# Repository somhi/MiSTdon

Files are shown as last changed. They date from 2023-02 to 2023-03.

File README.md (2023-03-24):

# MiSTdon - MiST addon 

This is a compendium of all that is needed to build a MiST prototype for any FPGA to be nearly compatible with the [MiST FPGA](https://github.com/mist-devel/mist-board/wiki).

Current status:

* [PCB design finished](MiSTdon.kicad/). Tests are Ok, but original firmware at 24 Mhz is giving bus noise, so **a** **modified firmware at 16 MHz is needed.**

* Working prototype made in a protoboard

* After a reset it stops working (see notes below) 
* Passive serial flashing of the FPGA has not been implemented as my FPGA does not have that possibility. I power supply the FPGA and MiST addon, then load the bitstream from the PC though JTAG.

Acknowledgements and thanks for help go to Jepalza, Volton and Manuferhi.

## Resources

* foroFPGA Jepalza's inspirational post http://www.forofpga.es/viewtopic.php?t=289

* MiST firmware
  * Source code https://github.com/mist-devel/mist-firmware
  
  * .bin latest binary firmware https://github.com/mist-devel/mist-binaries/tree/master/firmware
  
  * Flash firmware: [Atmel SAM-BA v2.18](https://www.microchip.com/developmenttools/ProductDetails/SAM-BA In-system Programmer). Follow [instructions](https://github.com/mist-devel/mist-board/wiki/HowToInstallTheFirmware).
    
    Note that the board cannot be programmed when the SD_CD signal is connected to GND.
  
* References [folder](references/)

## Materials

* USB Host Shield Mini (MAX3421E)  https://chome.nerpa.tech/arduino_usb_host_shield_projects/
  * Mini versión https://www.amazon.es/dp/B07Y83TJ47
  * Alternative https://es.aliexpress.com/item/1005002399157571.html
  
* SD card
  * https://digilent.com/shop/pmod-microsd-microsd-card-slot/
  * Alternative https://a.aliexpress.com/_EIKRgpj (SD module)
  
* AT91SAM7S256
  * MCUzone board http://www.mcuzone.com/shop/?product-6.html
    * https://a.aliexpress.com/_EuCplo9
  * Alternative Olimex board https://www.olimex.com/Products/ARM/Atmel/SAM7-H256/

* USB HUB  (optional). Can be any USB Hub, but if you want the reset button to work should be an IC like the FE2.1 used in MiSTer

## Pictures

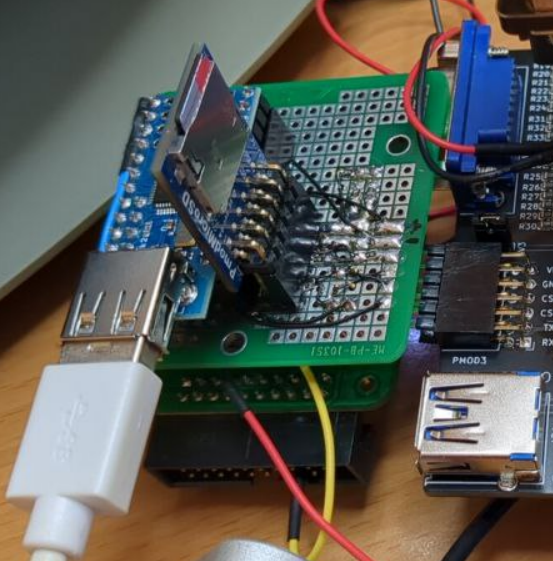
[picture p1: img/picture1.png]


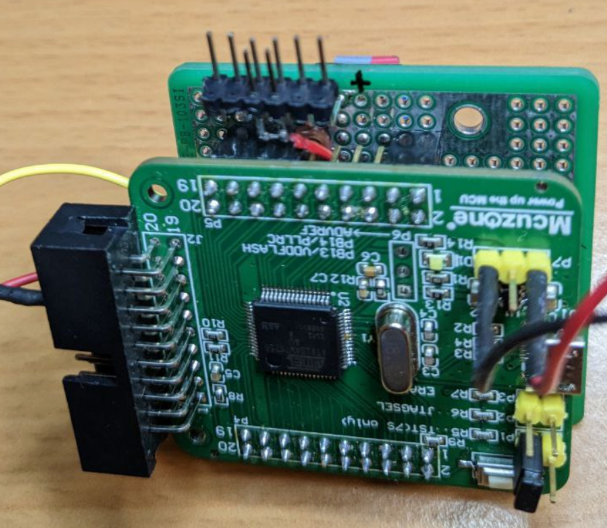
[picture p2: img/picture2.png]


## Main assembly tips

* Do not use Dupont wires for SPI lines
* Use SCK terminal resistors in all three SCK lines (47 Ohm is a good value)
* Attention must be paid to Reset signal (read below)

## Schematic

 [MiSTdon.pdf](MiSTdon.kicad/MiSTdon.pdf) contains a first draft of the schematic. All the related schematics where I based my design from are in the references [folder](references/Schematics/). 

Follows notes of what I have wired in my prototype.

#### **JTAG and Reset**

First diagram is already assembled in the MCUzone AT91SAM7S256 board.  

If you want to assemble your own PCB I've been told not to mount the electrolytic capacitor because it can make troubles. Have a look at the SiDi schematics.  

The reset signal is connected to the FPGA (not used), to the SAM, to the MAX and to the TUSB (HUB). 

This reset signal synchronizes the three ICs. If they are not synchronized, it does not recognize the USB.

The length of the reset signals between the MAX, the TUSB and the SAM is key. If they are unbalanced, it does not recognize the USB either. 

Without connecting the RST signal well, it will only work when it starts, but after a reset it will stop working.  

Thanks for the information to [Manuferhi](https://manuferhi.com/) (SiDi (MiST compatible) manufacturer).

In the schematics from other guys, they just connected the RST signal from MAX3421E directly to 3V3.

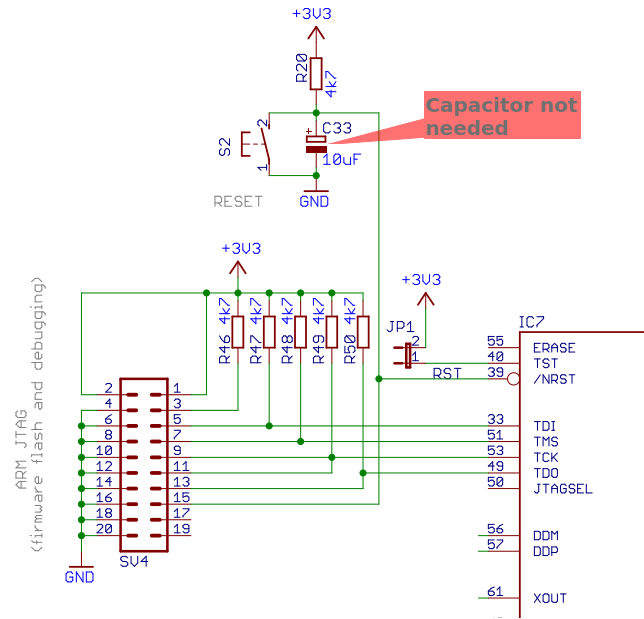
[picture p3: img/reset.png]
reset


#### **Main Circuit (SAM7s and MAX3421E)**

In green what I have connected in my prototype. 

In yellow optional parts. The INT interrupt signal might be optional but I have wired it anyway.

SCK terminal resistors marked in red are mandatory to stabilize the clock signal. As recommended by [Manuferhi](https://manuferhi.com/) (SiDi manufacturer), I have used 47 Ohm value resistors. 

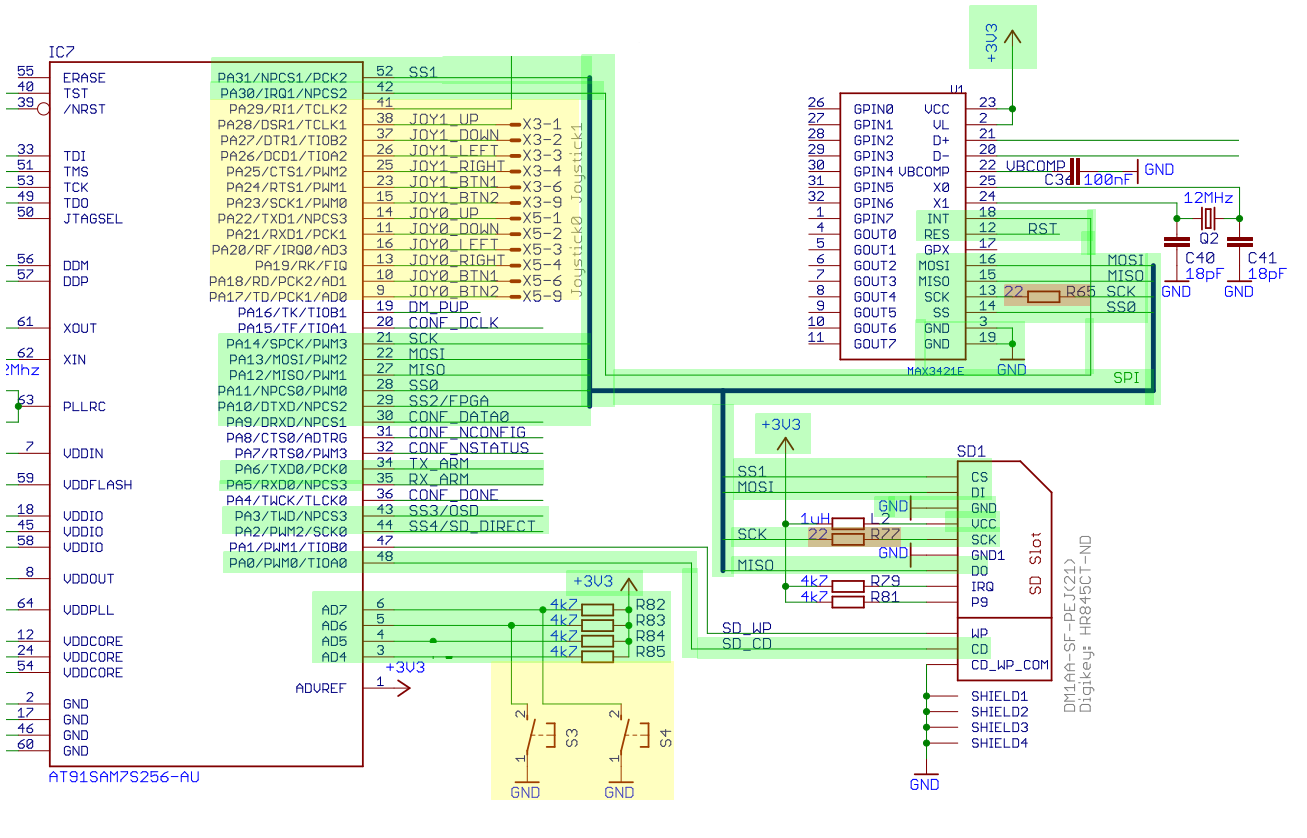
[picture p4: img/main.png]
main


#### FPGA connections

In green what I have connected in my prototype. 

In yellow optional parts. 

SCK terminal resistors marked in red are mandatory to stabilize the clock signal. As recommended by [Manuferhi](https://manuferhi.com/) (SiDi manufacturer), I have used 47 Ohm value resistors. 

Passive serial pins has not been connected as my [DECA FPGA](https://github.com/decafpga) does not have that possibility to flash cores.

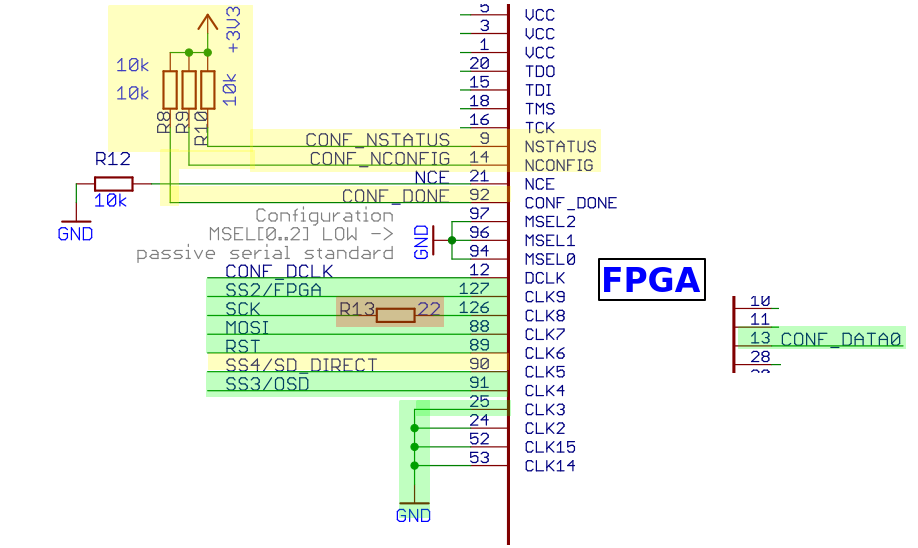
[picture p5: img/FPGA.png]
FPGA


## Pinouts

#### AT91SAM7S256 pinout (MCUzone)

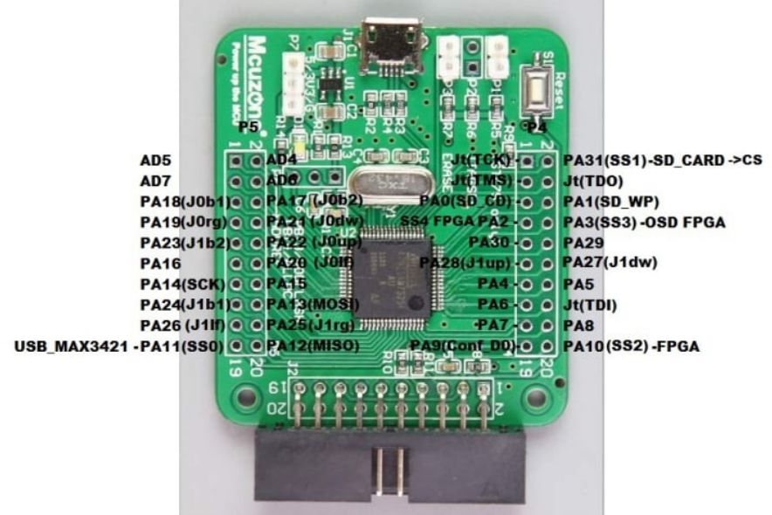
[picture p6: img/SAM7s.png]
SAM7s


Connections:

* J0, J1 are Joystick port signals (DB9) (not connected in my prototype)

* SD_CD signal to GND (or to the SD card module if has this signal)

  SD_ WP leave it unconnected

* AD6, AD7 connected to 3V3 pull-ups. If you add buttons like in the MiST schematic could be used as OSD and User buttons.

  AD4, AD7 connected to 3V3 pull-ups (in MiST schematic those inputs are connected to microswitches and are used to debug purposes like in ATARI core).

* MOSI, MISO, SCK connected to respective pins of SD Card, USB Host and FPGA boards

  * The Master is the AT91SAM7S256. All others are slave.
  * MOSI connects to FPGA DI pin
  * MISO connects to FPGA DO pin

* SS0 to USB Host shield (SS pin of MAX3421E)

* SS1 to SD card reader (CS pin)

* SS2, SS3, SS4, CONF_D0 to FPGA

  * SS2 is FPGA select signal
  * SS3 is OSD select signal 
  * CONF_D0 is User_io select signal
  * SS4 is SD direct signal (optional as is just used in a few cores)

* PA30 to INT signal of MAX3421E

* PA5 and PA6 are Rx/Tx signals respectively, and their purpose is to debug the MiST firmware.

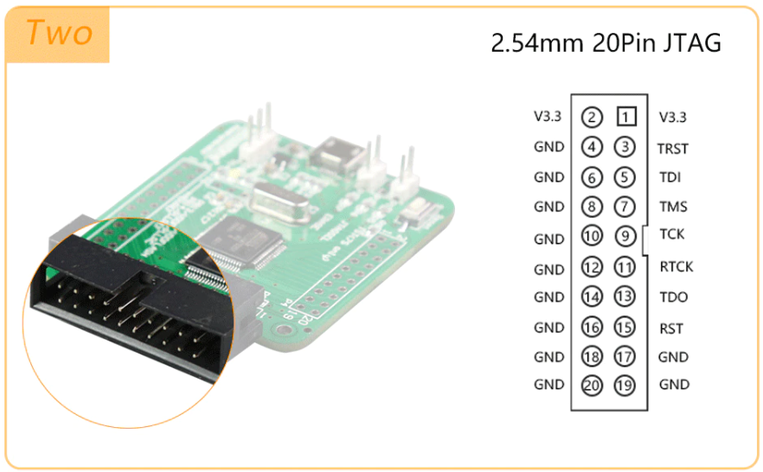
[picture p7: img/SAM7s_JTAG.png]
SAM7s_JTAG


Pins 3 and 15 are connected to the Reset button of the AT91SAM7S256 board.  **Please note that the above view on JTAG connector is from the cable point of view, not the connector. Check pin 1 on PCB silkscreen before connecting RST pin**.

In my prototype I connected one of those pins to the RST pin of MAX3421E.

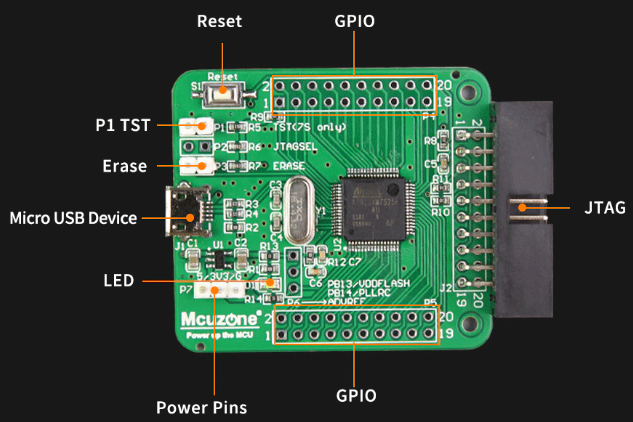
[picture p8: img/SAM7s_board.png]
SAM7s_board


#### USB Mini Host shield pinout (MAX3421E)

There is a typo in the silkscreen of USB Mini Host clones.  Just verify for yourself which ones are the correct MOSI and SCK pins.

A cut in the track to +5V should be made if you want maximum compatibility with 5V USB peripherals. 

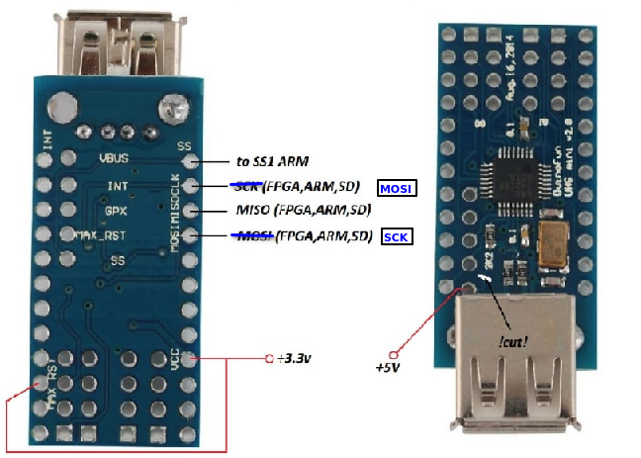
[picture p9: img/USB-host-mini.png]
USB-host-mini


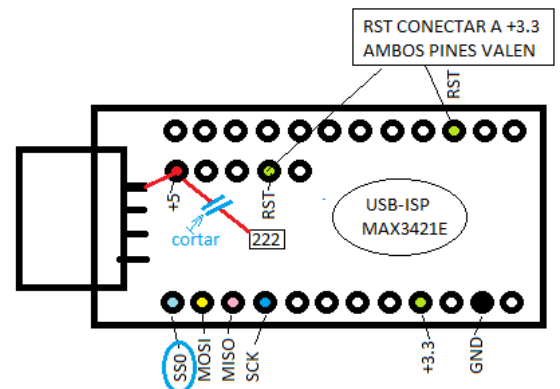
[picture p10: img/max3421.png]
max3421


#### Pmod SD card pinout (Digilent)

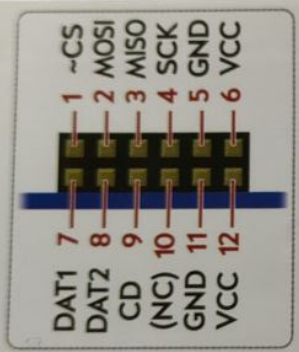
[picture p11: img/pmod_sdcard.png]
pmod_sdcard


#### Power supply

5V and GND from FPGA to the  AT91SAM7S256 board.  

3V3 and GND from FPGA (like PMOD connector) to the protoboard which power supply the Pmod SD card and the MAX3421E

5V from FPGA to the  VBUS pin of MAX3421E board.

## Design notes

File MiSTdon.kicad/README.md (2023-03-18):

# MiSTdon - KiCAD project

MiSTdon is an addon for any FPGA to be nearly compatible with the [MiST FPGA](https://github.com/mist-devel/mist-board/wiki) platform. 

Project has been developed with KiCAD 6.0.11. 

### Status

STATUS (17/03/23):  first PCB assembled. After first testing, all seems to work well.  Some changes will be introduced in next revision (see TODO list below).

STATUS (25/02/23):  prototype design work finished. v0.7 gerbers sent to JLCPCB for manufacturing.

### Credits

Acknowledgements and thanks for help go to Jepalza, Volton and Manuferhi.

### **Schematic**

 [MiSTdon.pdf](MiSTdon.pdf) 

### **Features**

* Socket for AT91SAM7S256 board (MCUzone)
* Socket for USB Host Shield Mini (MAX3421E) 
* PMOD for SD card (Digilent)
* PMOD for FPGA interface (fits nicely in [Deca retro cape 2](https://github.com/somhi/DECA_retro_cape_2))
* Two DB9 joystick ports
* OSD and USER button for core, and pins for SW2 debug buttons
* Reset button for ARM, USB and FPGA (if used)
* UART debug pins
* Passive serial pins
* Power pins

See main repository [Readme](../README.md) for materials list

### **Important Usage notes**

* **Better do not connect/disconnect interfaces while the board is powered**

* **Read jumper selection below.**

### **Jumper Selection**

Defaults are OPEN (jumper not placed or not soldered) and CLOSED (jumper placed or soldered)

* JP1 jumper closed connects 5V to USB VBus (**make sure before place jumper to cut the R222 track in MAX3421E USB Mini shield**). In case of doubt do not place this jumper, so not all USB peripherals will work at 3V3 which is applied to VBUS when jumper is disconnected.

* JP2 solder jumper. Central position with GND for SD Cards without this signal. Central position with CD for Digilent Pmod SD card.  In case of doubt solder central position and GND.

* JP3 place jumper in RST pins (leave GND pin unconnected).

### **Power supply and Reset external wires**

Connect wires from 5V and GND pins of P7 header (AT91SAM7S256 board) to J6 header 5V and GND pins.

Connect wire from 5V FPGA pin to J6 header 5V pin.  

Connect wire from RST pin 3 of JTAG header (AT91SAM7S256 board) to J6 header NRST pin.

### 3D model

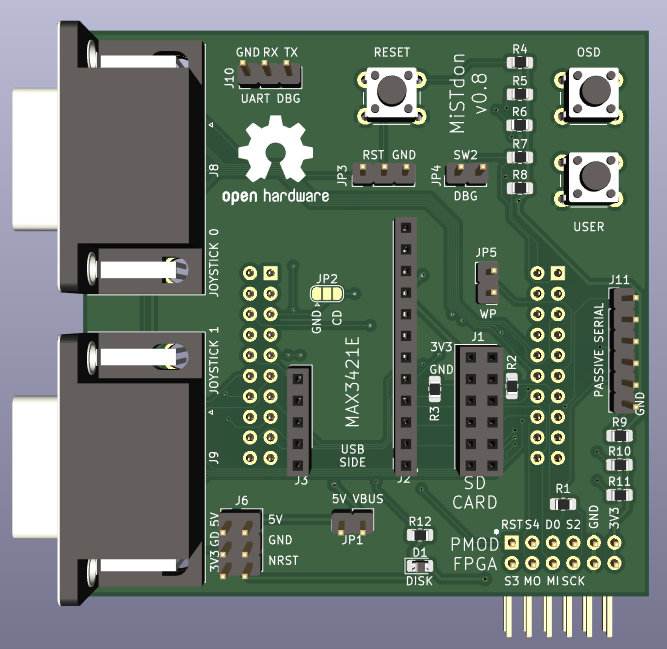
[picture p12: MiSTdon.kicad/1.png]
DECA_retro_cape_1


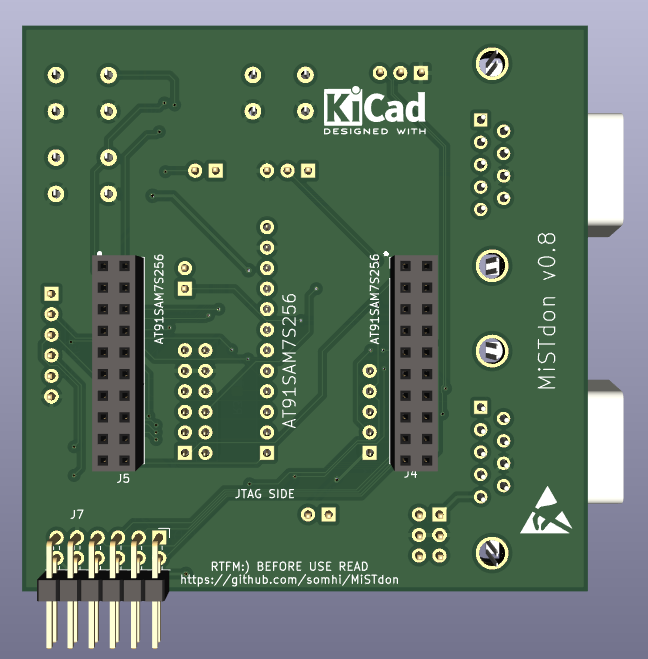
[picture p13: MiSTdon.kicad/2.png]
DECA_retro_cape_2


### Changelog

v0.7 finished prototype desing. Gerber sent to JLCPCB for manufacturing

v0.8 see changes below:

* change schematic text -> NRST WIRED EXTERNALLY TO SAM7S (JTAG PIN 3)
* R4 changed to 10K
* Move connector J6 to avoid collision with MAX3421E module
* Silkscreen changes: move MiSTdon text to a visible location, pmod sdcard gnd & 3V3, mark pin 1 in headers, notes to clarify orientation of MAX3421E and SAM7S

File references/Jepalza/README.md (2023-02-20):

### [Re: Adaptador "casi" compatible con MIST](http://www.forofpga.es/viewtopic.php?f=141&t=289#p1199)

- [Citar](http://www.forofpga.es/posting.php?mode=quote&f=141&p=1199)

[Mensaje ](http://www.forofpga.es/viewtopic.php?p=1199#p1199)por **[jepalza](http://www.forofpga.es/memberlist.php?mode=viewprofile&u=48)** » 04 Oct 2019, 10:37

Elementos necesarios:

-----PRIMERO-------
Placa principal, ARM de ATMEL, AT91SAM7S256, yo la compré directamente en OLIMEX (entiendo que es original), pero a un precio elevado, de 35€ (con gastos):
https://www.olimex.com/Products/ARM/Atmel/SAM7-H256/

Pero luego, un compañero (Fran, no doy mas datos, por que no le he pedido permiso para indicarlo)
me dijo que había una mas barata en Aliexpress, a un tercio de lo que yo pagué, por solo 12€:
[https://es.aliexpress.com/item/32826609 ... 2f01uWpreO](https://es.aliexpress.com/item/32826609273.html?spm=a219c.12010612.8148356.4.7e0a2f01uWpreO)

No es la misma, y cambian algunos pines, pero entiendo que es compatible 100%
Esta placa es necesario programar con el FIRM original de la MIST. Ver siguiente mensaje para ver cómo, por que , a pesar de ser fácil, tiene su complicación.

-----SEGUNDO----------
Lector de SD, esto, es para gustos. Yo he comprado uno con SD "normal" (no "micro") por tan solo 1€!!
Si el lector lleva pines WP y CD mejor, por que es mas compatible con el MIST, si no los lleva (como es mi caso), no pasa nada, se añaden puentes.

------TERCERO--------
Y por último, lector de USB a SPI, con Chip MAX3421E, solo 3€:
[https://es.aliexpress.com/item/32735946 ... b201603_52](https://es.aliexpress.com/item/32735946108.html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,searchweb201602_,searchweb201603_52)

(nota, si lo buscas por separado, no busques MAX3421 por que no aparece casi nada, busca por "Host USB compatible con Google ADK para Arduino")

De esta placa, hay oficiales, y clones. Los clones han invertido por error, la serigrafía de los pines MOSI y SCK. Hay mucha info por la red sobre este fallo. Yo lo corroboro, por que miré los pines uno a uno, y realmente están invertidos ambos.
Imaginaros el problema que tuve durante días, por que no funcionaba. Le dí mil vueltas al tema sin saber por que no funcionaba. Hasta que leí lo del fallo. Fue cambiar un pin por otro, y a la primera funcionó.
Ademas, en estas placas MAX3421 Clón hay otro problema, y es que, vienen "atadas" a 3.3v fijos para alimentar el USB, lo que hace que muchos teclados no funcionen por que no loes llega los 5v. necesarios. En cambio, los ratones a 3.3v funcionan la mayoría.
La solución está en internet, en muchas páginas, pero resumo diciendo, que solo es cortar una pista y alimentar ese pin por separado a +5v.
Lo indico en el dibujo esquemático.

En total, solo 35+1+3=39€ (en mi caso, al comprar el ARM mas caro), pero si compras el ARM barato, solo 12+1+3=15 euros!!!!

Notas sobre el "esquema" (por llamarlo de algún modo, por que es un simple BMP hecho a mano con PAINT):
Su construcción es simple, lo mas importante, son los pines MISO, MOSI y SCK, por que deben ir de módulo en módulo, o sea, de la FPGA, al ARM, a la SD y al USB-MAX (no importa el orden). Luego, cada módulo SPI lleva su "SS", que son: (según esquema MIST)
SS0=USB, SS1=SD, SS2=FPGA y SS3=OSD-ATMEL-ARM. Luego, tenemos el SS4, que yo NO he conectado, por que es para acceso directo a SD desde la FPGA, para que algunos cores usen la SD sin pasar por el ARM, pero sinceramente, no he visto ningún core (de los que he probado) que lo use, por lo tanto, a pesar de que lo tengo reservado en el conector, no lo tengo cableado.

El MIST necesita pines de la SD llamados CD y WP (Card Detect y Write Protect), y como mi lector SD de un euro no lleva, tengo puenteados a GND (activos) el del CD, pero el del WP lo tengo "abierto", por que entiendo que de ese modo se permite grabar en la SD (no lo he probado).

La placa USB-SPI lleva un pin RST que activado es a +3.3v. En la placa Clón de 3€, he visto (y leído por la red) que DEBE estar siempre activo, o sea, puenteado a +3.3v para que se inicie siempre en modo 12mhz de velocidad (reloj externo). No sé si esto es cierto, pero lo que si es verdad, es que, sin ese puente a +3.3, la placa no se detecta por el ARM, y los USB no funcionan. Por lo tanto, puente a +3.3 "con la clónica", por que con la oficial debe de llevar un "pull-up" con resistencia y no es necesario.

Hablando de "pull-up", la placa MIST lleva tres pulsadores y dos puentes en placa. Realmente NO SON necesarios para nosotros, peeerooo... si no los llevamos a +3.3 (con resistencias de 4k7, 4 en total), el menú se vuelve inestable. Sin el "pull-up", al entrar al menu con el teclado USB (tecla F12), una de cada tres, se sale del menú sin motivo. Por eso, en la versión final he añadido las cuatro resistencias, a los 4 pines AD de la placa ARM (AD4 al 7). Y de paso, he puesto dos pulsadores y dos puentes. Uno de los pulsadores es MENU (AD6), el otro es programable por el CORE (AD7), y los puentes son AD4 y 5 son para programación de la placa ARM desde su conector o para depuración (por ejemplo, el AD5 puenteado, hace que el core del Atari ST aparezca un contador de direcciónes.)
Sinceramente, solo veo útil el del Menú. El resto, no pondría nada. De hecho , el AD7 "NO" lo tengo conectado (pero si llevado a su R4k7) por que en la placa olimex ARM mia, el pin AD7 está "fuera" del conector, y es necesario soldar un cable aparte, y como no lo uso, no lo he soldado.

En cuanto a alimentación, se puede hacer TODO a 3.3v, pero como ya he comentado, hay teclados USB que no funcionan a 3.3v. Y luego, si lo hacemos todo a 3.3, la placa FPGA se resiente del consumo. Por eso, es mejor como he hecho yo, que es, usar el regulador de 5v a 3.3 de cada módulo. Los módulos de SD y ARM, ambos llevan regulador a 3.3, por eso, los alimento a +5v. cogidos de la FPGA. En cambio, la placa USB-SPI solo funciona a 3.3v, pero cortando la pista indicada, puedo meter 5v. directos al USB, y la placa alimentarla a 3.3v, cogidos del propio ARM (de su salida de 3.3v)

El RESET "no" lo he conectado. En la MIST hay un pulsador RST para todo (FPGA, ARM, MAX3421), pero yo no los uso. Para mi, resetear es "apagar y encender", mas sencillo, menos cables.... (así de simple)

El conector que he preparado para la FPGA, es compatible con la IV y la V (las de "aliexpress", claro).

Y de eso precisamente hablo ahora, de las FPGA: compilar CORES de la MIST para este "invento mio" es ultrasimple.
Coger los fuentes de la MIST, cambiar de FPGA (de cyclone III a cyclone IV o V), cambiar reloj de 27 a 50mhz, y poner estos pines:

CÓDIGO: [SELECCIONAR TODO](http://www.forofpga.es/viewtopic.php?f=141&t=289#)

```
set_global_assignment -name FAMILY "Cyclone IV E
set_global_assignment -name DEVICE EP4CE22F17C8
#
set_location_assignment PIN_E1 -to CLOCK_50
set_location_assignment PIN_M8 -to LED
set_location_assignment PIN_J16 -to botones[0]
set_location_assignment PIN_J15 -to botones[1]
#
# VGA 666 (LA MARCA DEL DIABLO)
set_location_assignment PIN_F8 -to VGA_R[0]
set_location_assignment PIN_G1 -to VGA_R[1]
set_location_assignment PIN_L3 -to VGA_R[2]
set_location_assignment PIN_E6 -to VGA_R[3]
set_location_assignment PIN_G5 -to VGA_R[4]
set_location_assignment PIN_L4 -to VGA_R[5]
#
set_location_assignment PIN_L8 -to VGA_B[0]
set_location_assignment PIN_K5 -to VGA_B[1]
set_location_assignment PIN_L1 -to VGA_B[2]
set_location_assignment PIN_N1 -to VGA_B[3]
set_location_assignment PIN_P1 -to VGA_B[4]
set_location_assignment PIN_R1 -to VGA_B[5]
#
set_location_assignment PIN_L7 -to VGA_G[0]
set_location_assignment PIN_M10 -to VGA_G[1]
set_location_assignment PIN_L2 -to VGA_G[2]
set_location_assignment PIN_N2 -to VGA_G[3]
set_location_assignment PIN_P2 -to VGA_G[4]
set_location_assignment PIN_T2 -to VGA_G[5]
#
set_location_assignment PIN_K1 -to VGA_HS
set_location_assignment PIN_K2 -to VGA_VS
#
# Control de la placa compatible MIST
set_location_assignment PIN_B16 -to SPI_DO
set_location_assignment PIN_C15 -to SPI_DI
set_location_assignment PIN_C16 -to SPI_SCK
set_location_assignment PIN_D15 -to SPI_SS2
set_location_assignment PIN_F15 -to SPI_SS3
set_location_assignment PIN_D16 -to CONF_DATA0
#set_location_assignment PIN_F16 -to SPI_SS4 # no cableado, pero tampoco he visto que se use!!!
#
# SONIDO
set_location_assignment PIN_J2 -to AUDIO_L
set_location_assignment PIN_J1 -to AUDIO_R
#
# SDRAM Unamiga
set_location_assignment PIN_B10 -to SDRAM_A[0]
set_location_assignment PIN_A11 -to SDRAM_A[1]
set_location_assignment PIN_B11 -to SDRAM_A[2]
set_location_assignment PIN_A12 -to SDRAM_A[3]
set_location_assignment PIN_D14 -to SDRAM_A[4]
set_location_assignment PIN_D12 -to SDRAM_A[5]
set_location_assignment PIN_D11 -to SDRAM_A[6]
set_location_assignment PIN_C14 -to SDRAM_A[7]
set_location_assignment PIN_C11 -to SDRAM_A[8]
set_location_assignment PIN_C9 -to SDRAM_A[9]
set_location_assignment PIN_A10 -to SDRAM_A[10]
set_location_assignment PIN_C8 -to SDRAM_A[11]
set_location_assignment PIN_C6 -to SDRAM_A[12]
#
set_location_assignment PIN_A2 -to SDRAM_DQ[0]
set_location_assignment PIN_B3 -to SDRAM_DQ[1]
set_location_assignment PIN_A3 -to SDRAM_DQ[2]
set_location_assignment PIN_B4 -to SDRAM_DQ[3]
set_location_assignment PIN_A4 -to SDRAM_DQ[4]
set_location_assignment PIN_B5 -to SDRAM_DQ[5]
set_location_assignment PIN_A5 -to SDRAM_DQ[6]
set_location_assignment PIN_B6 -to SDRAM_DQ[7]
set_location_assignment PIN_A14 -to SDRAM_DQ[8]
set_location_assignment PIN_B13 -to SDRAM_DQ[9]
set_location_assignment PIN_A13 -to SDRAM_DQ[10]
set_location_assignment PIN_B12 -to SDRAM_DQ[11]
set_location_assignment PIN_D6 -to SDRAM_DQ[12]
set_location_assignment PIN_D5 -to SDRAM_DQ[13]
set_location_assignment PIN_C3 -to SDRAM_DQ[14]
set_location_assignment PIN_D3 -to SDRAM_DQ[15]
#
set_location_assignment PIN_A15 -to SDRAM_CKE
set_location_assignment PIN_B14 -to SDRAM_CLK
set_location_assignment PIN_A7 -to SDRAM_nCAS
set_location_assignment PIN_D8 -to SDRAM_nRAS
set_location_assignment PIN_B7 -to SDRAM_nWE
set_location_assignment PIN_E8 -to SDRAM_nCS
#
set_location_assignment PIN_E9 -to SDRAM_BA[0]
set_location_assignment PIN_D9 -to SDRAM_BA[1]
#
set_location_assignment PIN_A6 -to SDRAM_DQML
set_location_assignment PIN_E11 -to SDRAM_DQMH
```

Aquí indico los de la Cyclone IV del UnAmiga con la "txapela" de Antonio Villena, para tener acceso a la VGA y al sonido. El teclado, lógico, sería por USB, lo mismo que los mandos de juego.

Los pines mas importantes y distintos a lo conocido, son los "compatibles" SPI del MIST

Nota: no se pueden subir cores con el menú, por que no está cableados los pines JTAG de la MIST. Es mas, juraría que no se puede, por que uno de los pines queda oculto bajo la FPGA (si me equivoco, corregidme), pero se podría intentar, mirando el esquema MIST, se pueden llevar los cables del ARM al JTAG, y ver que pasa. (quizás un día me anime yo ha probarlo)

actualización:
comentar, que para "compilar" (sintetizar) un core propio de la MIST, ademas de los pines indicados aquí arriba, y de cambiar el reloj "clock_27" por uno de 50, probablemente, haya que añadir un "reset" a la línea que corresponda dentro del código. En este caso, yo he llamado "botones" a los dos pulsadores de la FPGA. Sería añadir a la línea que sea, esto: " || ~botones[0]" para que ademas de los puntos de "reset" del core, como el del OSD, o el botón físico de la MIST, tengamos el nuestro.
Ejemplo, en el core del "PLUS_TOO" (el del mac128), la línea original es:

CÓDIGO: [SELECCIONAR TODO](http://www.forofpga.es/viewtopic.php?f=141&t=289#)

```
		if(!pll_locked || status[0] || status_reset || buttons[1] ||
			rom_download || (last_mem_config != status_mem)) 
```

Y al añadir "nuestro" reset:

CÓDIGO: [SELECCIONAR TODO](http://www.forofpga.es/viewtopic.php?f=141&t=289#)

```
		if(!pll_locked || status[0] || status_reset || ~botones[0] || buttons[1] ||
			rom_download || (last_mem_config != status_mem)) 
```

Si os fijáis, en el original tenemos un "buttons[1]" que es el boon de reinicio de la MIST. Este botón lo podemos añadir físicamente en nuestra placa, o usar los de la FPGA, que es mas sencillo.

Y creo que está todo explicado....

(bueno, una cosa mas, que los USB se pueden enchufar en "caliente", o sea, puedes arrancar un juego de CPC usando el teclado, y cuando el juego está en marcha, cambiar el teclado por un mando USB, y funciona)

### [Re: Adaptador "casi" compatible con MIST](http://www.forofpga.es/viewtopic.php?f=141&t=289#p1200)

- [Citar](http://www.forofpga.es/posting.php?mode=quote&f=141&p=1200)

[Mensaje ](http://www.forofpga.es/viewtopic.php?p=1200#p1200)por **[jepalza](http://www.forofpga.es/memberlist.php?mode=viewprofile&u=48)** » 04 Oct 2019, 10:38

Programar ATMEL At91SAM7

Primero, poner jumper J1, enchufar arm y esperar 10 segundos.
soltar arm, dejar J1 abierto de nuevo, y enchufar otra vez. nos detecta puerto com nuevo
arrancar sam-ba, cargar el firm "mist-binaries-master/firmware/firmware_190820.bin"
en "scripts" elegir "erase all flash", y pulsar execute, nos pregunta si queremos desbloquear regiones
decimos SI, ahora, pulsamos en send file, se envia, tarda muy poco, y nos pregunta de nuevo
si queremos bloquear regiones, decimos que NO, y listo, ya esta

sam-ba 2.12
https://armbedded.taskit.de/node/8
http://download.armbedded.eu/tools/sam-ba_2.12.exe

mist firm:
https://github.com/mist-devel/mist-binaries

mist instrucciones flash arm:
[https://github.com/mist-devel/mist-boar ... heFirmware](https://github.com/mist-devel/mist-board/wiki/HowToInstallTheFirmware)
[https://github.com/mist-devel/mist-boar ... er-windows](https://github.com/mist-devel/mist-board/wiki/HowToInstallTheFirmware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)
(buscar seccion SAM-BA, los pasos son correctos al 100% en todo, incluso lo del J1)

Esto que parece sencillo en un principio, me llevo una hora entera, por que el PC no me detectaba la placa, por mas que probé a puentear J1.
Al final, de esas cosas que dices "que conyo ha pasado aquí!!!", tanto enchufa, desenchufa, puentea J1, despuentea J1, en una de esas, lo cogió.
Por lo tanto, no puedo dar fé de que el proceso sea sencillo y directo a la primera. Solo indico, que al final, tras detectarlo el PC, el resot, fue coser y cantar, a la primera, y en menos de un minuto estaba lista. Pero hasta que llegó ese minuto, fue desesperante.!!!!

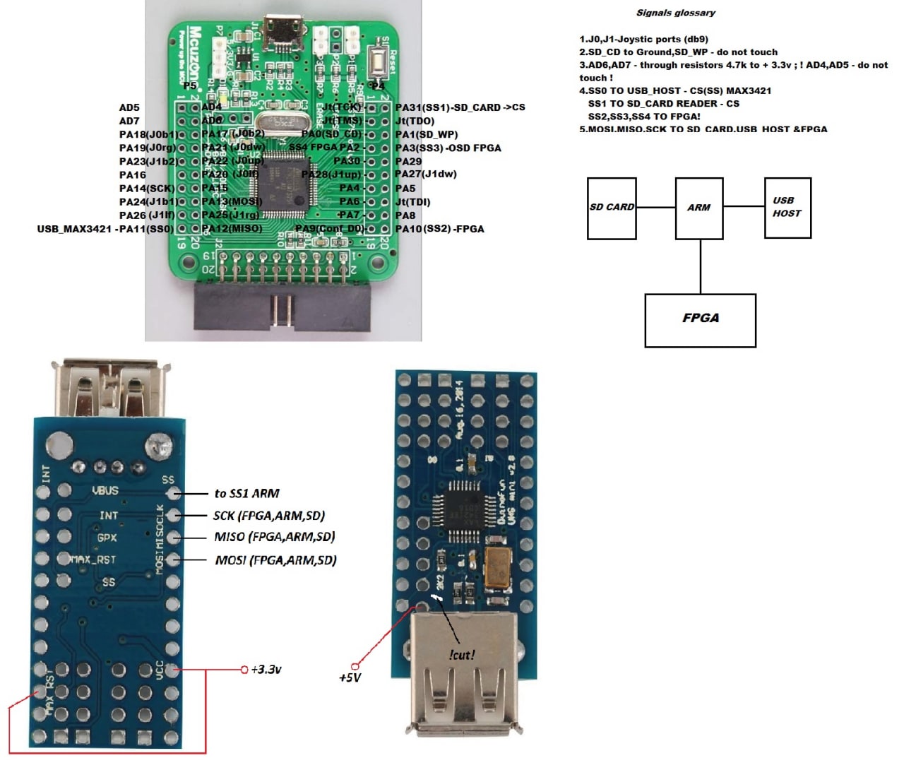
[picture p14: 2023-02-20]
references/Schematics/MiST_volton.jpg

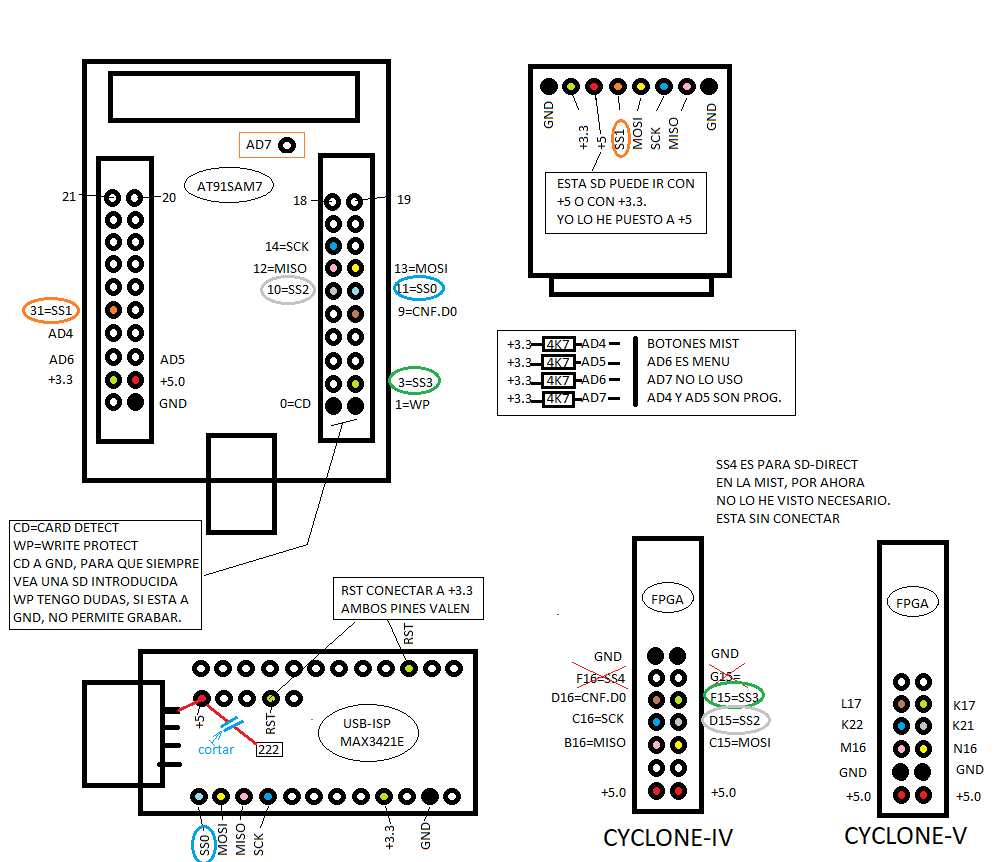
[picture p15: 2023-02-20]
references/Schematics/MiST_Jepalza.png

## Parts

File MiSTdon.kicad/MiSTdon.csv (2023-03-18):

Source: | /home/jordi/Coding/Kicad/a_MiST/MiSTdon_GitHub/MiSTdon.kicad/MiSTdon.kicad_sch
Date: | Sat 18 Mar 2023 12:57:08 CET
Tool: | Eeschema 6.0.11-2627ca5db0~126~ubuntu22.04.1
Generator: | /usr/share/kicad/plugins/bom_csv_grouped_by_value.py
Component Count: | 32
Individual Components:
Item | Qty | Reference(s) | Value | LibPart | Footprint | Datasheet
 |  | D1 | LED | Device:LED | Diode_SMD:D_0805_2012Metric_Pad1.15x1.40mm_HandSolder | ~
 |  | J1 | Conn_02x06_Top_Bottom | Connector_Generic:Conn_02x06_Top_Bottom | libraries:Pmod_2x06_P2.54mm_Vertical_2 | ~
 |  | J2 | Conn_01x12 | Connector_Generic:Conn_01x12 | Connector_PinSocket_2.54mm:PinSocket_1x12_P2.54mm_Vertical | ~
 |  | J3 | Conn_01x05 | Connector_Generic:Conn_01x05 | Connector_PinSocket_2.54mm:PinSocket_1x05_P2.54mm_Vertical | ~
 |  | J4 | Conn_02x10_Odd_Even | Connector_Generic:Conn_02x10_Odd_Even | Connector_PinSocket_2.54mm:PinSocket_2x10_P2.54mm_Vertical | ~
 |  | J5 | Conn_02x10_Odd_Even | Connector_Generic:Conn_02x10_Odd_Even | Connector_PinSocket_2.54mm:PinSocket_2x10_P2.54mm_Vertical | ~
 |  | J6 | Conn_02x03_Odd_Even | Connector_Generic:Conn_02x03_Odd_Even | Connector_PinHeader_2.54mm:PinHeader_2x03_P2.54mm_Vertical | ~
 |  | J7 | Conn_02x06_Top_Bottom | Connector_Generic:Conn_02x06_Top_Bottom | libraries:PMOD_Female_Horizontal_2 | ~
 |  | J8 | DB9_Male | Connector:DB9_Male | Connector_Dsub:DSUB-9_Male_Horizontal_P2.77x2.84mm_EdgePinOffset9.90mm_Housed_MountingHolesOffset11.32mm | ~
 |  | J9 | DB9_Male | Connector:DB9_Male | Connector_Dsub:DSUB-9_Male_Horizontal_P2.77x2.84mm_EdgePinOffset9.90mm_Housed_MountingHolesOffset11.32mm | ~
 |  | J10 | Conn_01x03 | Connector_Generic:Conn_01x03 | Connector_PinHeader_2.54mm:PinHeader_1x03_P2.54mm_Vertical | ~
 |  | J11 | Conn_01x06 | Connector_Generic:Conn_01x06 | Connector_PinHeader_2.54mm:PinHeader_1x06_P2.54mm_Vertical | ~
 |  | JP1 | Conn_01x02 | Connector_Generic:Conn_01x02 | Connector_PinHeader_2.54mm:PinHeader_1x02_P2.54mm_Vertical | ~
 |  | JP2 | SolderJumper_3_Open | Jumper:SolderJumper_3_Open | Jumper:SolderJumper-3_P1.3mm_Open_RoundedPad1.0x1.5mm | ~
 |  | JP3 | Conn_01x03 | Connector_Generic:Conn_01x03 | Connector_PinHeader_2.54mm:PinHeader_1x03_P2.54mm_Vertical | ~
 |  | JP4 | Conn_01x02 | Connector_Generic:Conn_01x02 | Connector_PinHeader_2.54mm:PinHeader_1x02_P2.54mm_Vertical | ~
 |  | JP5 | Conn_01x02 | Connector_Generic:Conn_01x02 | Connector_PinHeader_2.54mm:PinHeader_1x02_P2.54mm_Vertical | ~
 |  | R1 | 47 | Device:R | Resistor_SMD:R_0805_2012Metric_Pad1.20x1.40mm_HandSolder | ~
 |  | R2 | 47 | Device:R | Resistor_SMD:R_0805_2012Metric_Pad1.20x1.40mm_HandSolder | ~
 |  | R3 | 47 | Device:R | Resistor_SMD:R_0805_2012Metric_Pad1.20x1.40mm_HandSolder | ~
 |  | R4 | 10k | Device:R | Resistor_SMD:R_0805_2012Metric_Pad1.20x1.40mm_HandSolder | ~
 |  | R5 | 4k7 | Device:R | Resistor_SMD:R_0805_2012Metric_Pad1.20x1.40mm_HandSolder | ~
 |  | R6 | 4k7 | Device:R | Resistor_SMD:R_0805_2012Metric_Pad1.20x1.40mm_HandSolder | ~
 |  | R7 | 4k7 | Device:R | Resistor_SMD:R_0805_2012Metric_Pad1.20x1.40mm_HandSolder | ~
 |  | R8 | 4k7 | Device:R | Resistor_SMD:R_0805_2012Metric_Pad1.20x1.40mm_HandSolder | ~
 |  | R9 | 10k | Device:R | Resistor_SMD:R_0805_2012Metric_Pad1.20x1.40mm_HandSolder | ~
 |  | R10 | 10k | Device:R | Resistor_SMD:R_0805_2012Metric_Pad1.20x1.40mm_HandSolder | ~
 |  | R11 | 10k | Device:R | Resistor_SMD:R_0805_2012Metric_Pad1.20x1.40mm_HandSolder | ~
 |  | R12 | 220 | Device:R | Resistor_SMD:R_0805_2012Metric_Pad1.20x1.40mm_HandSolder | ~
 |  | SW1 | SW_Push | Switch:SW_Push | Button_Switch_THT:SW_PUSH_6mm_H5mm | ~
 |  | SW3 | SW_Push | Switch:SW_Push | Button_Switch_THT:SW_PUSH_6mm_H5mm | ~
 |  | SW4 | SW_Push | Switch:SW_Push | Button_Switch_THT:SW_PUSH_6mm_H5mm | ~
Collated Components:
Item | Qty | Reference(s) | Value | LibPart | Footprint | Datasheet
1 | 1 | D1 | LED | Device:LED | Diode_SMD:D_0805_2012Metric_Pad1.15x1.40mm_HandSolder | ~
2 | 1 | J1 | Conn_02x06_Top_Bottom | Connector_Generic:Conn_02x06_Top_Bottom | libraries:Pmod_2x06_P2.54mm_Vertical_2 | ~
3 | 1 | J2 | Conn_01x12 | Connector_Generic:Conn_01x12 | Connector_PinSocket_2.54mm:PinSocket_1x12_P2.54mm_Vertical | ~
4 | 1 | J3 | Conn_01x05 | Connector_Generic:Conn_01x05 | Connector_PinSocket_2.54mm:PinSocket_1x05_P2.54mm_Vertical | ~
5 | 2 | J4, J5 | Conn_02x10_Odd_Even | Connector_Generic:Conn_02x10_Odd_Even | Connector_PinSocket_2.54mm:PinSocket_2x10_P2.54mm_Vertical | ~
6 | 1 | J6 | Conn_02x03_Odd_Even | Connector_Generic:Conn_02x03_Odd_Even | Connector_PinHeader_2.54mm:PinHeader_2x03_P2.54mm_Vertical | ~
7 | 1 | J7 | Conn_02x06_Top_Bottom | Connector_Generic:Conn_02x06_Top_Bottom | libraries:PMOD_Female_Horizontal_2 | ~
8 | 2 | J8, J9 | DB9_Male | Connector:DB9_Male | Connector_Dsub:DSUB-9_Male_Horizontal_P2.77x2.84mm_EdgePinOffset9.90mm_Housed_MountingHolesOffset11.32mm | ~
9 | 2 | J10, JP3 | Conn_01x03 | Connector_Generic:Conn_01x03 | Connector_PinHeader_2.54mm:PinHeader_1x03_P2.54mm_Vertical | ~
10 | 1 | J11 | Conn_01x06 | Connector_Generic:Conn_01x06 | Connector_PinHeader_2.54mm:PinHeader_1x06_P2.54mm_Vertical | ~
11 | 3 | JP1, JP4, JP5 | Conn_01x02 | Connector_Generic:Conn_01x02 | Connector_PinHeader_2.54mm:PinHeader_1x02_P2.54mm_Vertical | ~
12 | 1 | JP2 | SolderJumper_3_Open | Jumper:SolderJumper_3_Open | Jumper:SolderJumper-3_P1.3mm_Open_RoundedPad1.0x1.5mm | ~
13 | 3 | R1, R2, R3 | 47 | Device:R | Resistor_SMD:R_0805_2012Metric_Pad1.20x1.40mm_HandSolder | ~
14 | 4 | R4, R9, R10, R11 | 10k | Device:R | Resistor_SMD:R_0805_2012Metric_Pad1.20x1.40mm_HandSolder | ~
15 | 4 | R5, R6, R7, R8 | 4k7 | Device:R | Resistor_SMD:R_0805_2012Metric_Pad1.20x1.40mm_HandSolder | ~
16 | 1 | R12 | 220 | Device:R | Resistor_SMD:R_0805_2012Metric_Pad1.20x1.40mm_HandSolder | ~
17 | 3 | SW1, SW3, SW4 | SW_Push | Switch:SW_Push | Button_Switch_THT:SW_PUSH_6mm_H5mm | ~

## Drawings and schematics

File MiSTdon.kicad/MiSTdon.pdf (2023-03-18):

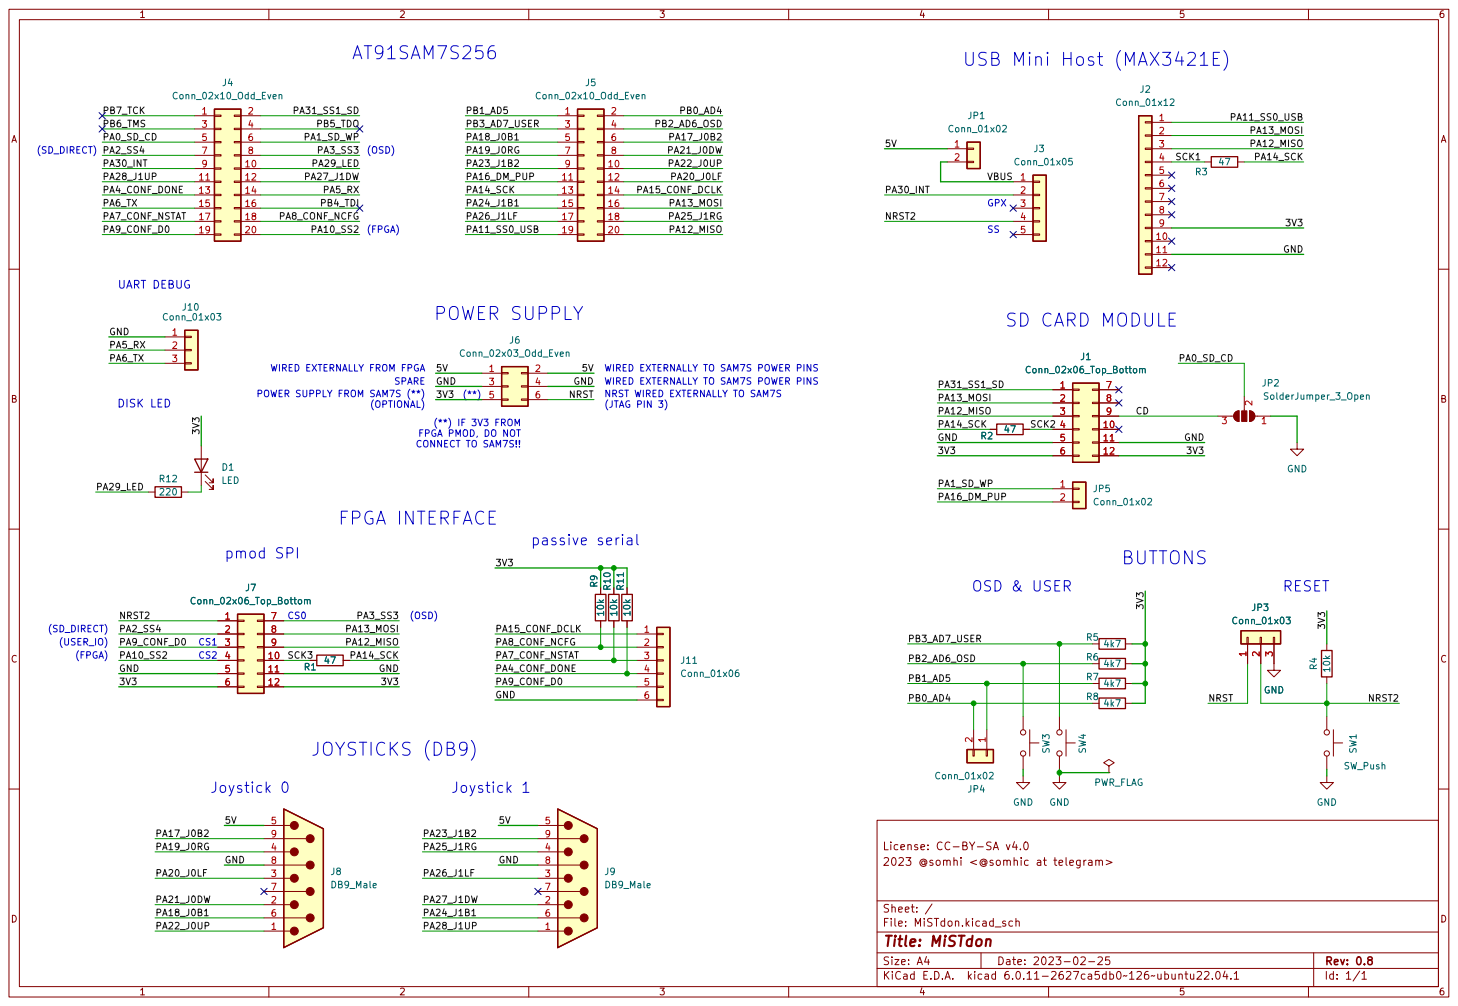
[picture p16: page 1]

PA14_SCK WIRED EXTERNALLY FROM FPGA JOYSTICKS (DB9)

WIRED EXTERNALLY TO SAM7S POWER PINS

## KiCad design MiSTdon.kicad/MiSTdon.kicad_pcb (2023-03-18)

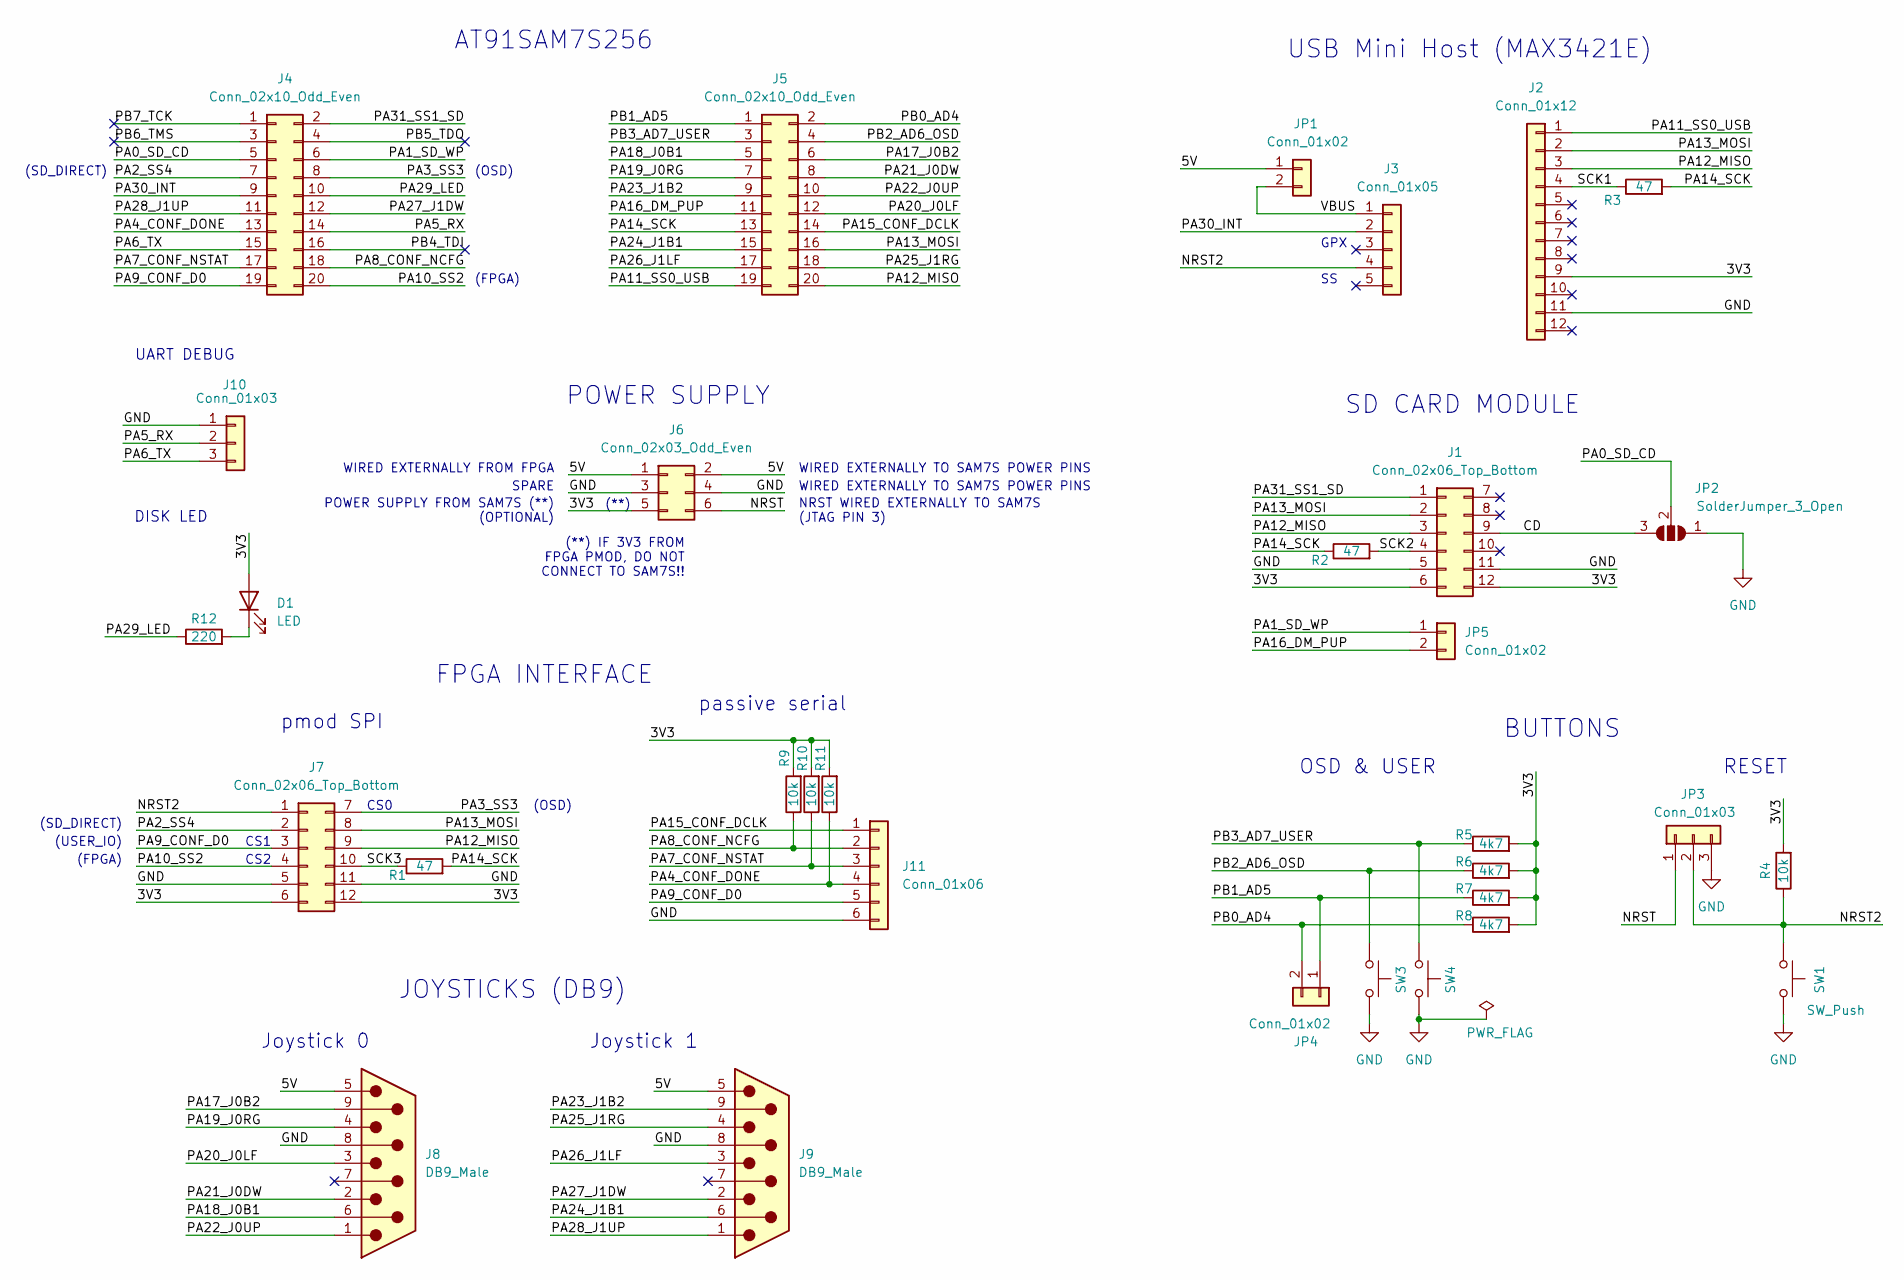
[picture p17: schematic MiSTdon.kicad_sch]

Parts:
D1: LED; D_0805_2012Metric_Pad1.15x1.40mm_HandSolder
J1: Conn_02x06_Top_Bottom; Pmod_2x06_P2.54mm_Vertical_2
J2: Conn_01x12; PinSocket_1x12_P2.54mm_Vertical
J3: Conn_01x05; PinSocket_1x05_P2.54mm_Vertical
J4, J5: Conn_02x10_Odd_Even; PinSocket_2x10_P2.54mm_Vertical
J6: Conn_02x03_Odd_Even; PinHeader_2x03_P2.54mm_Vertical
J7: Conn_02x06_Top_Bottom; PMOD_Female_Horizontal_2
J8, J9: DB9_Male; DSUB-9_Male_Horizontal_P2.77x2.84mm_EdgePinOffset9.90mm_Hou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
J10: Conn_01x03; PinHeader_1x03_P2.54mm_Vertical
J11: Conn_01x06; PinHeader_1x06_P2.54mm_Vertical
JP1, JP4, JP5: Conn_01x02; PinHeader_1x02_P2.54mm_Vertical
JP2: SolderJumper_3_Open; SolderJumper-3_P1.3mm_Open_RoundedPad1.0x1.5mm
JP3: Conn_01x03; PinHeader_1x03_P2.54mm_Vertical
R1, R2, R3: 47; R_0805_2012Metric_Pad1.20x1.40mm_HandSolder
R4, R9, R10, R11: 10k; R_0805_2012Metric_Pad1.20x1.40mm_HandSolder
R5, R6, R7, R8: 4k7; R_0805_2012Metric_Pad1.20x1.40mm_HandSolder
R12: 220; R_0805_2012Metric_Pad1.20x1.40mm_HandSolder
SW1, SW3, SW4: SW_Push; SW_PUSH_6mm_H5mm

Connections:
/3V3: D1.2 (A), J1.6, J1.12, J2.9, J6.5, J7.6, J7.12, R4.2, R5.2, R6.2, R7.2, R8.2, R9.2, R10.2, R11.2
/5V: J6.1, J6.2, J8.5, J9.5, JP1.1
/CD: J1.9, JP2.3 (B)
/NRST: J6.6, JP3.1
/NRST2: J3.4, J7.1, JP3.2, R4.1, SW1.1
/PA0_SD_CD: J4.5, JP2.2 (C)
/PA1_SD_WP: J4.6, JP5.1
/PA2_SS4: J4.7, J7.2
/PA3_SS3: J4.8, J7.7
/PA4_CONF_DONE: J4.13, J11.4, R11.1
/PA5_RX: J4.14, J10.2
/PA6_TX: J4.15, J10.3
/PA7_CONF_NSTAT: J4.17, J11.3, R10.1
/PA8_CONF_NCFG: J4.18, J11.2, R9.1
/PA9_CONF_D0: J4.19, J7.3, J11.5
/PA10_SS2: J4.20, J7.4
/PA11_SS0_USB: J2.1, J5.19
/PA12_MISO: J1.3, J2.3, J5.20, J7.9
/PA13_MOSI: J1.2, J2.2, J5.16, J7.8
/PA14_SCK: J5.13, R1.2, R2.1, R3.2
/PA15_CONF_DCLK: J5.14, J11.1
/PA16_DM_PUP: J5.11, JP5.2
/PA17_J0B2: J5.6, J8.9
/PA18_J0B1: J5.5, J8.6
/PA19_J0RG: J5.7, J8.4
/PA20_J0LF: J5.12, J8.3
/PA21_J0DW: J5.8, J8.2
/PA22_J0UP: J5.10, J8.1
/PA23_J1B2: J5.9, J9.9
/PA24_J1B1: J5.15, J9.6
/PA25_J1RG: J5.18, J9.4
/PA26_J1LF: J5.17, J9.3
/PA27_J1DW: J4.12, J9.2
/PA28_J1UP: J4.11, J9.1
/PA29_LED: J4.10, R12.1
/PA30_INT: J3.2, J4.9
/PA31_SS1_SD: J1.1, J4.2
/PB0_AD4: J5.2, JP4.2, R8.1
/PB1_AD5: J5.1, JP4.1, R7.1
/PB2_AD6_OSD: J5.4, R6.1, SW3.1
/PB3_AD7_USER: J5.3, R5.1, SW4.1
/PB4_TDI: J4.16
/PB5_TDO: J4.4
/PB6_TMS: J4.3
/PB7_TCK: J4.1
/SCK1: J2.4, R3.1
/SCK2: J1.4, R2.2
/SCK3: J7.10, R1.1
/VBUS: J3.1, JP1.2
GND: J1.5, J1.11, J2.11, J6.3, J6.4, J7.5, J7.11, J8.8, J9.8, J10.1, J11.6, JP2.1 (A), JP3.3, SW1.2, SW3.2, SW4.2
unnamed: D1.1 (K), R12.2

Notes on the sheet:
WIRED EXTERNALLY FROM FPGA
CS1
(SD_DIRECT)
USB Mini Host (MAX3421E)
CS2
GPX
UART DEBUG
(**) IF 3V3 FROM FPGA PMOD, DO NOT CONNECT TO SAM7S!!
JOYSTICKS (DB9)
Joystick 0
OSD & USER
(OSD)
WIRED EXTERNALLY TO SAM7S POWER PINS
Joystick 1
POWER SUPPLY FROM SAM7S (**) (OPTIONAL)
passive serial
FPGA INTERFACE
(**)
(USER_IO)
POWER SUPPLY
DISK LED
SPARE
BUTTONS
CS0
RESET
(FPGA)
SD CARD MODULE
AT91SAM7S256
NRST WIRED EXTERNALLY TO SAM7S (JTAG PIN 3)
pmod SPI

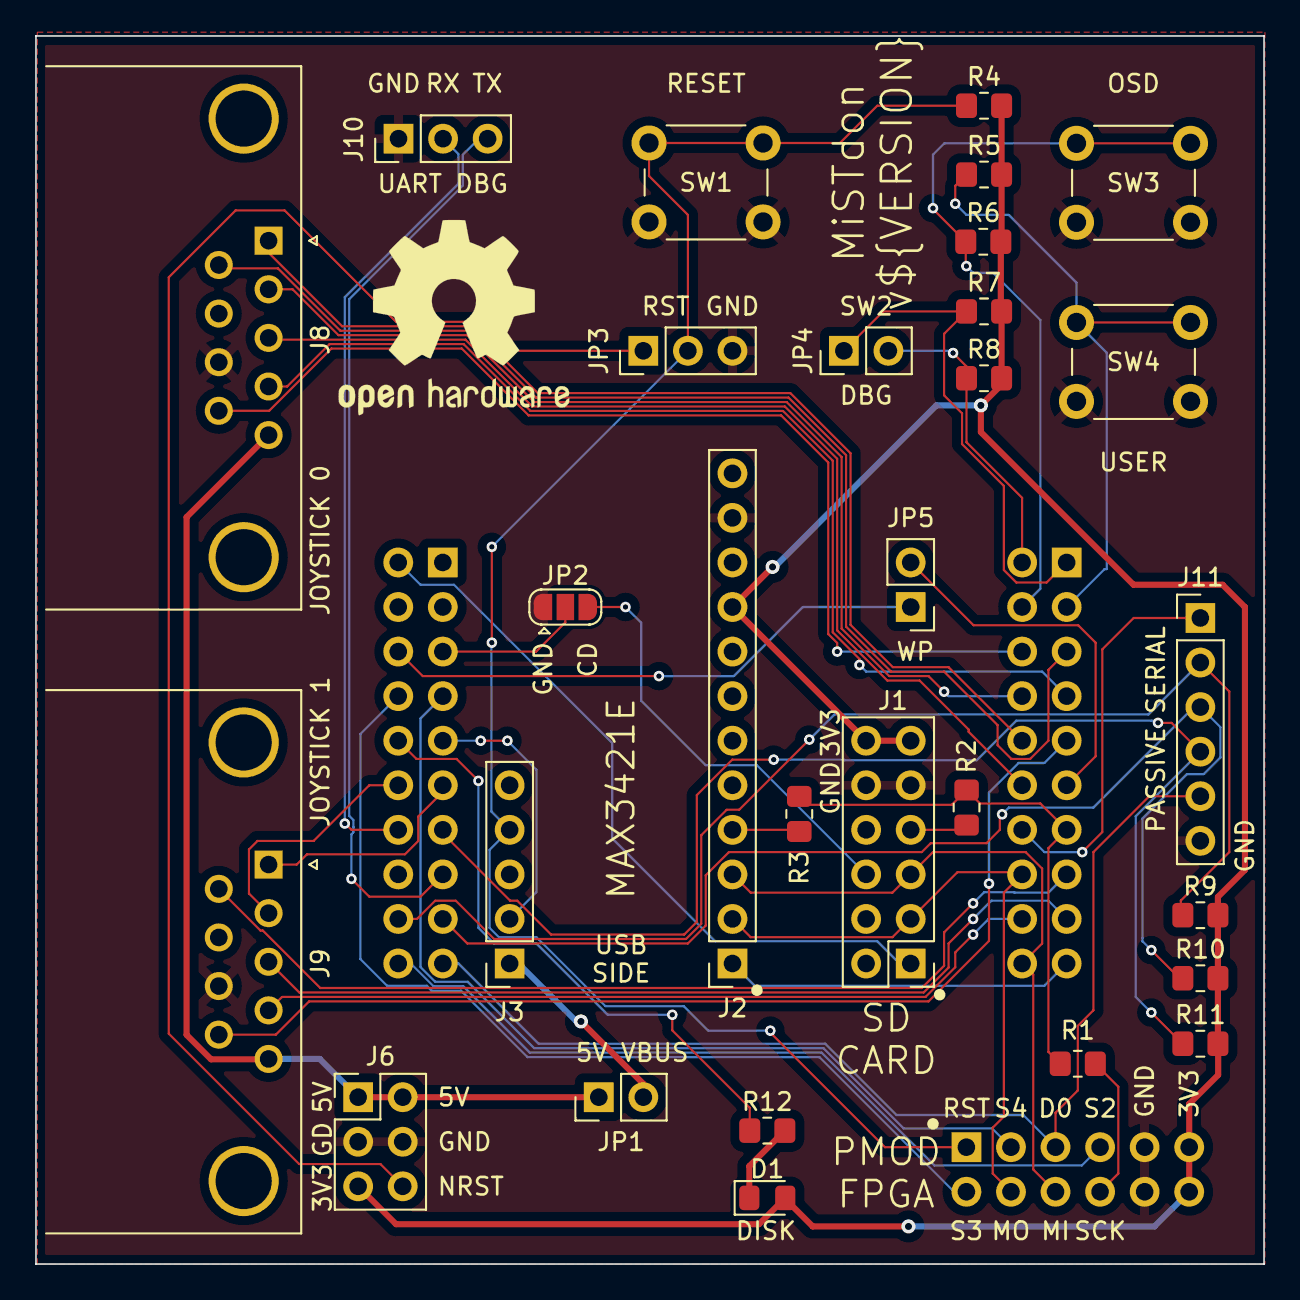
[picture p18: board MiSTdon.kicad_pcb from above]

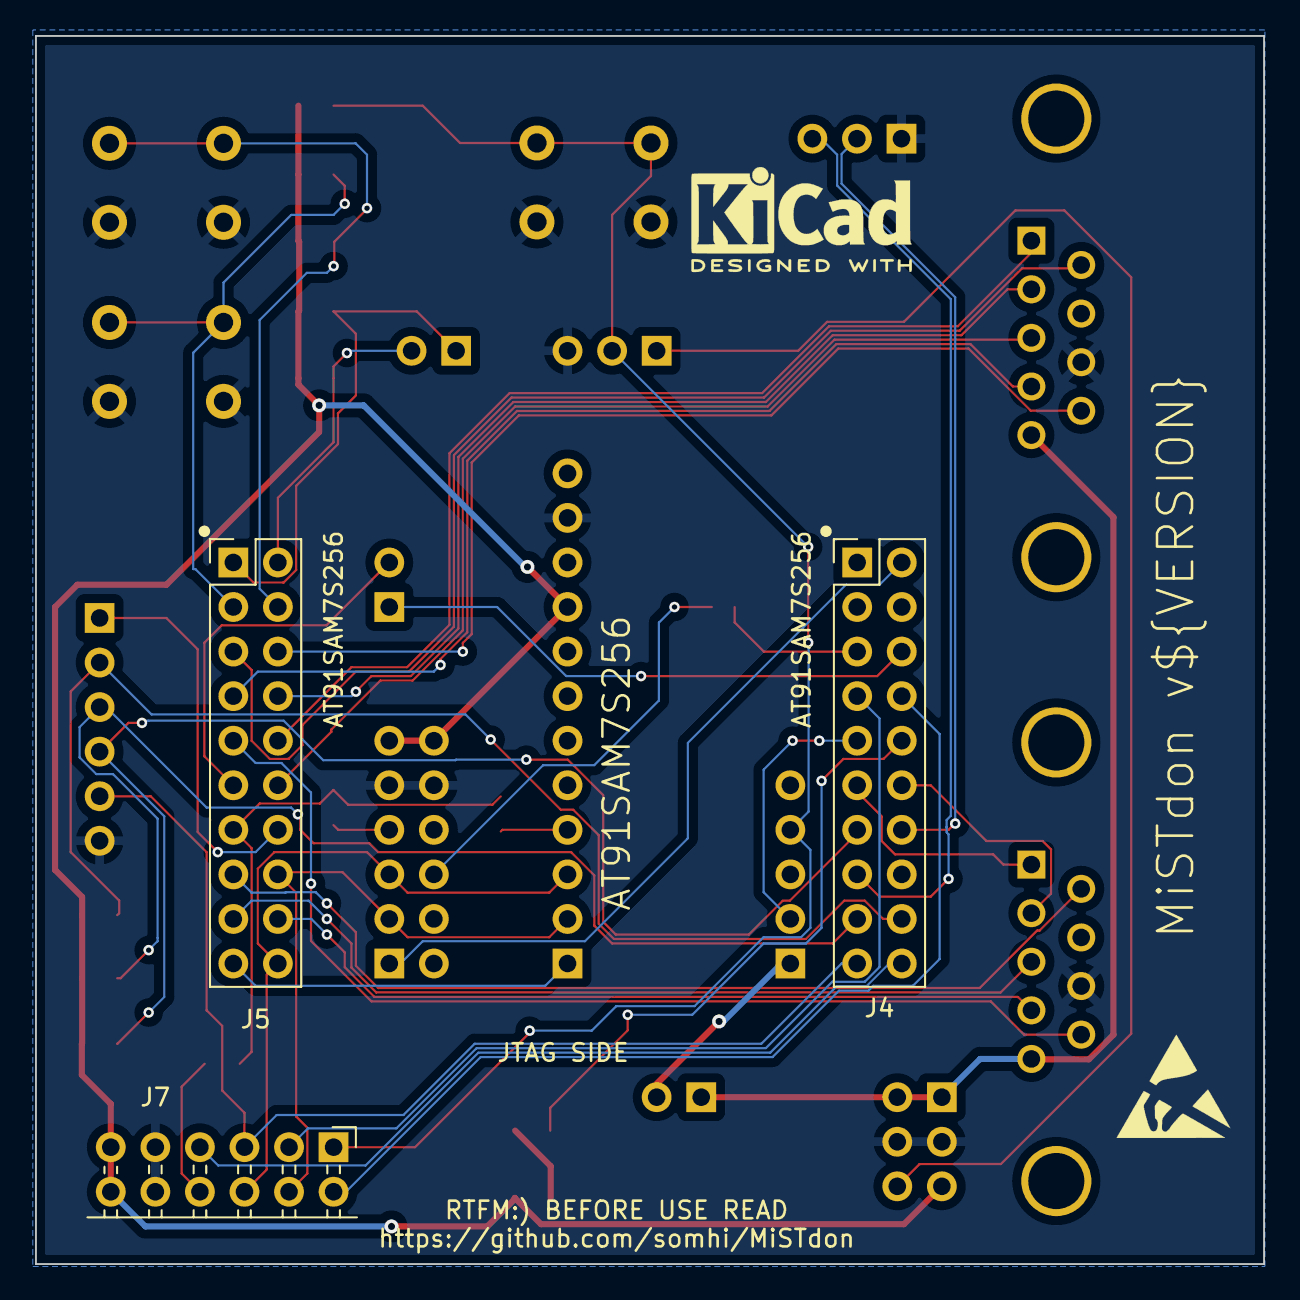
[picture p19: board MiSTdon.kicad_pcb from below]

Board: 2 copper layers, 70.0 x 70.0 mm, 34 parts (4 on the bottom side), 47 nets.

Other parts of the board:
LO2: OSHW-Logo2_14.6x12mm_SilkScreen
LO4: ESD-Logo_6.6x6mm_SilkScreen

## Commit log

2023-02-21 added schematic draft
2023-02-24 added kicad WIP and firmware 16 MHz
    [MiSTdon.kicad_pcb, MiSTdon.kicad_sch]
2023-02-24 pcb draft
    [MiSTdon.kicad_pcb, MiSTdon.kicad_sch]
2023-02-25 Kicad done, missing routing
    [MiSTdon.kicad_pcb, MiSTdon.kicad_sch]
2023-02-25 v0.7 PCB gerbers generated for manufacturing
    [MiSTdon-B_Cu.gbl, MiSTdon-B_Mask.gbs, MiSTdon-B_Paste.gbp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]
2023-02-25 v0.7 renamed gerber file
2023-03-18 v0.8 some changes after testing first PCB
    [MiSTdon-B_Cu.gbl, MiSTdon-B_Mask.gbs, MiSTdon-B_Paste.gbp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]

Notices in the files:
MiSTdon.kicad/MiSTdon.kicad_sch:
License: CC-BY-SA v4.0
